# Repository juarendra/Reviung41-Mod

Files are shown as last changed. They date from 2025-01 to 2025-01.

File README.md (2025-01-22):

# Reviung41-Mod
This is MOD for Reviung41 Keyboard

## Table of Content
* [Product Specsification](#product-specsification)
* [Download VIA](#download-via)
* [Load JSON File](#Load-JSON-File)
* [Link Keycode QMK](#Link-keycode-qmk)
* [Tutorial VIA Usage](#tutorial-via-usage)
* [Cara Setting Knob](#cara-setting-knob)
* [How To use MACRO](#how-to-use-macro)
* [Preview Hardware](#preview-hardware)
* [Preview VIA](#preview-via)
* [Cara Update/Upgrade Firmware](#cara-update/upgrade-firmware)
* [Documentation](#documentation)
  * [Pinout Diagram](#pinout-diagram)
  * [Dimension](#dimension)
  * [BOM](#bom)
  * [Schematic](#schematic)
  * [Example Program](#examples-program)
* [FAQ](#FAQ)

## Product Specsification
- Arduino Pro Micro Type C as Microcontroller
- QMK Firmware
- Support VIA, all key can proggrammed
- RGB Underglow or RGB Matrix per key
- 4x Layer 
- Hotswap Switch
- 3D Case 
- Reviung41 Layout
- OLED Screen 

## Download VIA
Link Download VIA(CHOSEE BASED YOUR OS) : https://github.com/the-via/releases/releases
VIA WEB VERSION : https://usevia.app/

## Link Keycode QMK
- mouse : https://github.com/qmk/qmk_firmware/blob/master/docs/feature_mouse_keys.md
- keyboard : https://github.com/qmk/qmk_firmware/blob/master/docs/keycodes.md

## Tutorial VIA Usage
- https://docs.keeb.io/via

## Cara Setting Knob
- Untuk melakukan setting di knob perlu memasukan command berupa keycode qmk, Jadi cara nya sama dengan melakuykan setting dengan Any key seperti petunjuk pada link berikut: 
https://docs.keeb.io/via

Here's some examples:

- LALT(KC_TAB) - Sends Alt-Tab
- LCTL(KC_C) - Sends Ctrl-C
- LGUI(KC_C) - Sends Cmd-C or Win-C
- LSFT(LCTL(KC_END)) - Sends Shift-Ctrl-End
- MO(1) - Momentarily turn on layer 1
- LCA(KC_DEL) - Sends Ctrl-Alt-Del
- MT(MOD_RSFT, KC_ENT) - Sends Shift if held, Enter if tapped
- MACRO (0) - macro 0

## How To use MACRO
you can read on [this file](https://github.com/juarendra/STREAMPAD-QMK-VIA/blob/main/DOC/MACRO%20VIA%20USAGE.pdf)
or you can read on this [web](https://www.keychron.com/blogs/archived/how-to-use-via-to-program-your-keyboard)
or you can see video [youtube](https://youtu.be/GtSeo69Y0Zw)

## Preview Hardware
<p align="center">
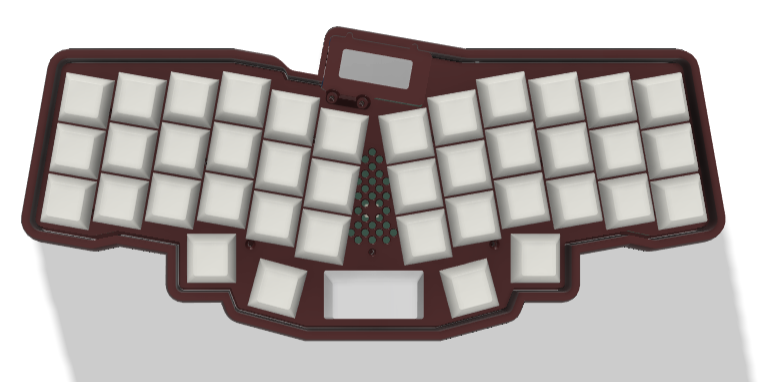
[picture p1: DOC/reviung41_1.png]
  
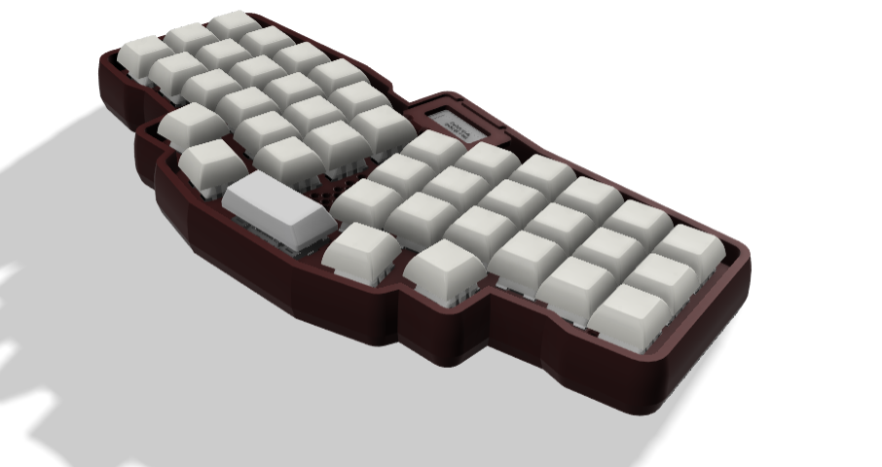
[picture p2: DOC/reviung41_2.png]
  
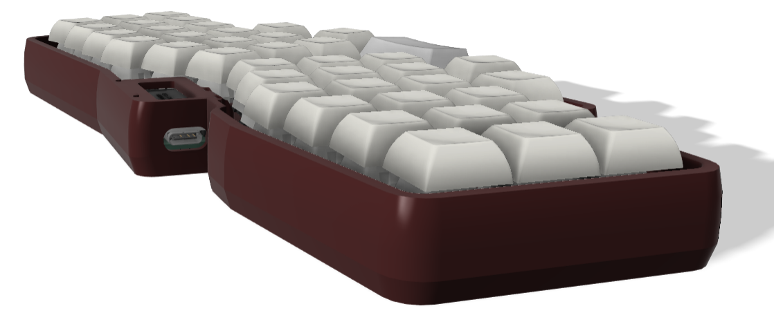
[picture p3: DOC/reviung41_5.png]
  
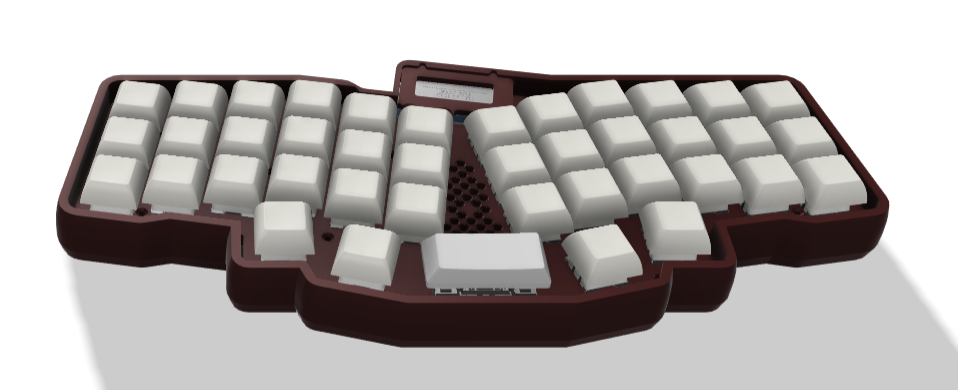
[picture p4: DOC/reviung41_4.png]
  
</p>

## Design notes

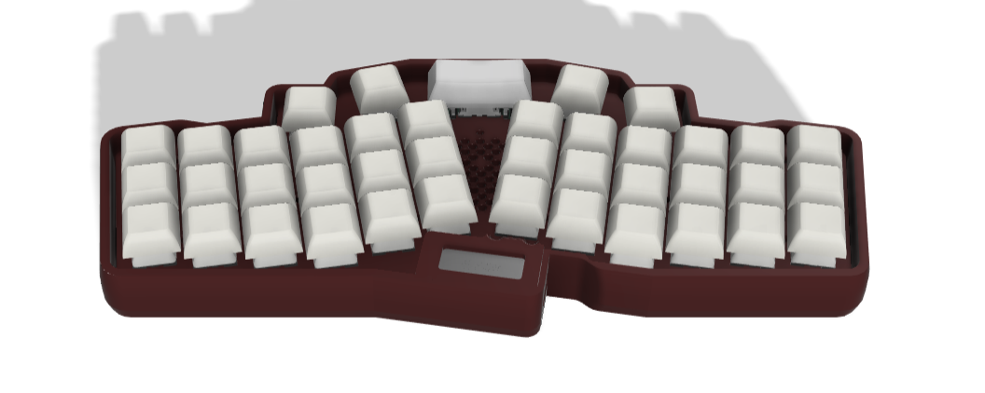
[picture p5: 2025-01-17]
DOC/reviung41_3.png

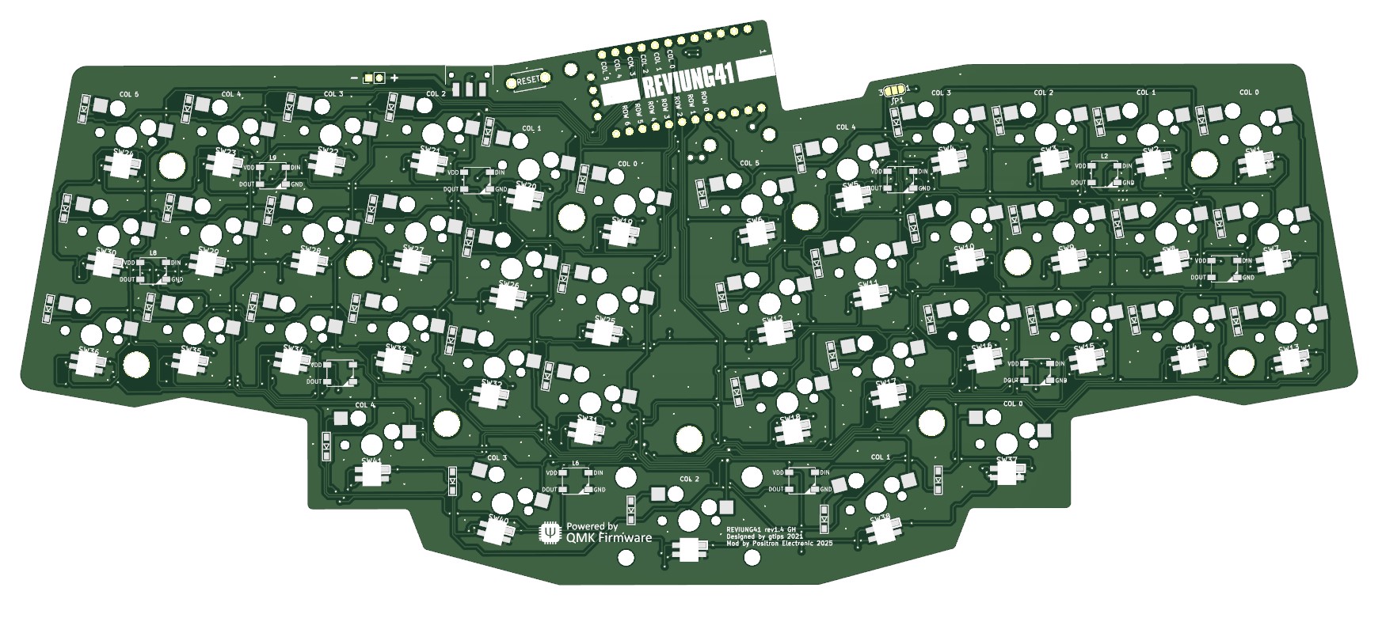
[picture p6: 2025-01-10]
DOC/BOTTOM_PCB.jpg

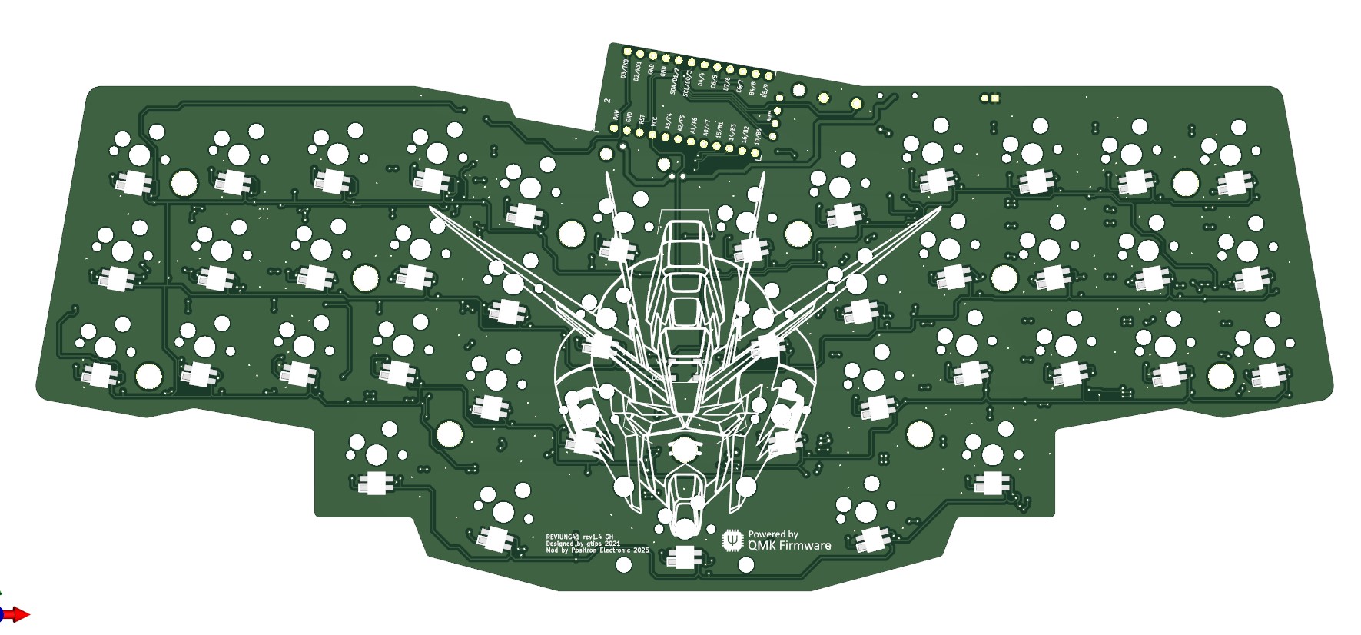
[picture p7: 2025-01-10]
DOC/TOP_PCB.jpg

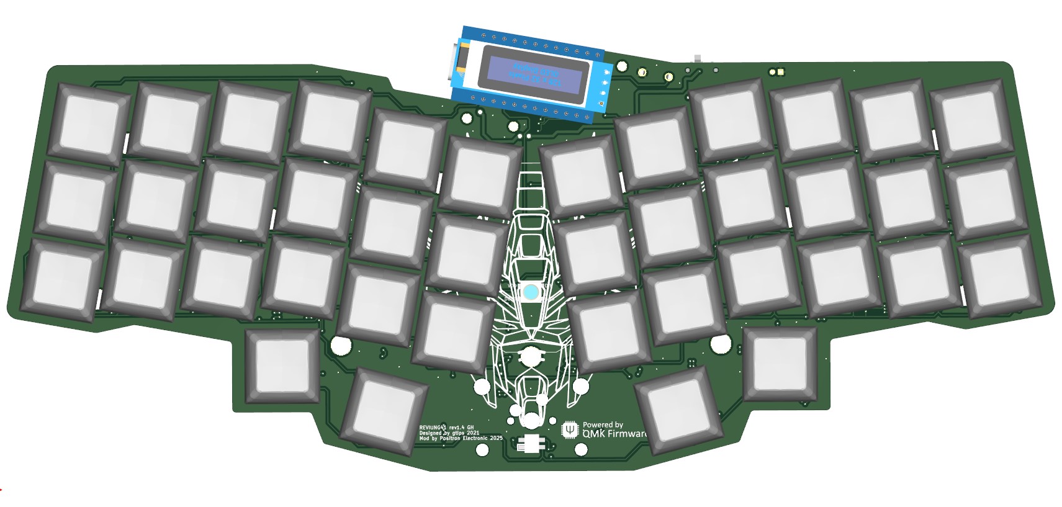
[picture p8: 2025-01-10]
DOC/TOP_PCB1.jpg

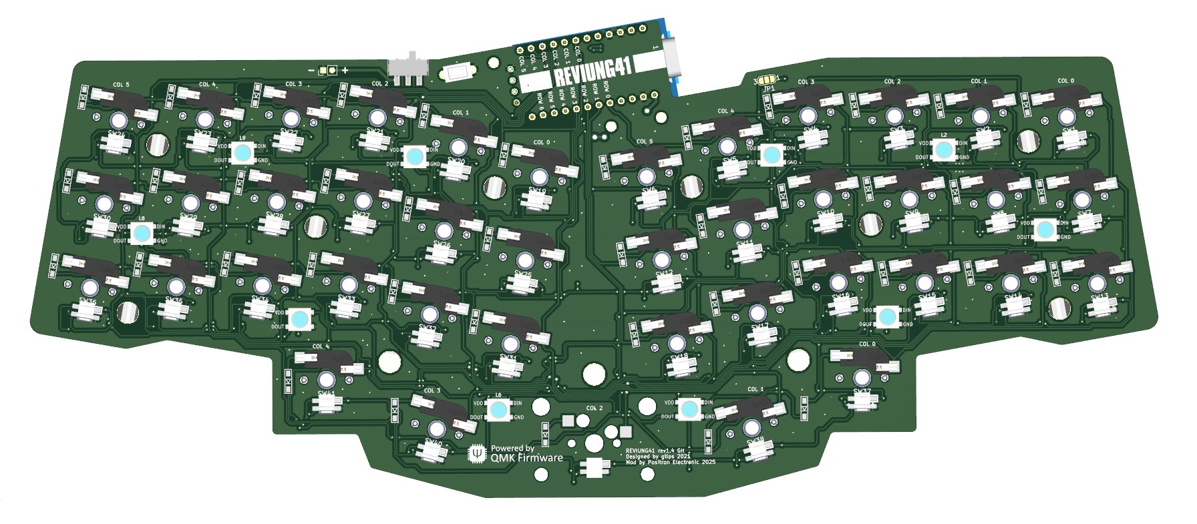
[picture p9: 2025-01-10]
DOC/BOTTOM_PCB1.jpg

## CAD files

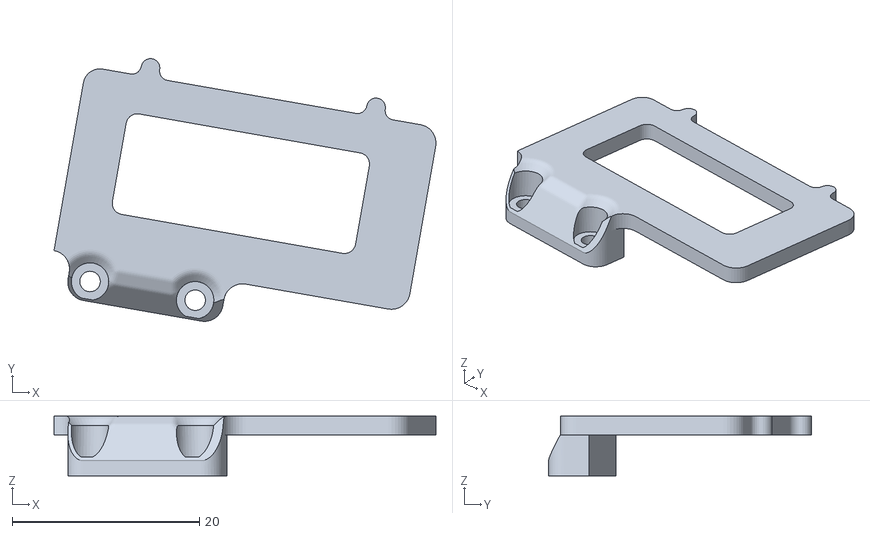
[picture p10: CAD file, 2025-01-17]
HARDWARE/CASE/Oled_case_reviung41.stl
40.8 x 28.1 x 6.36

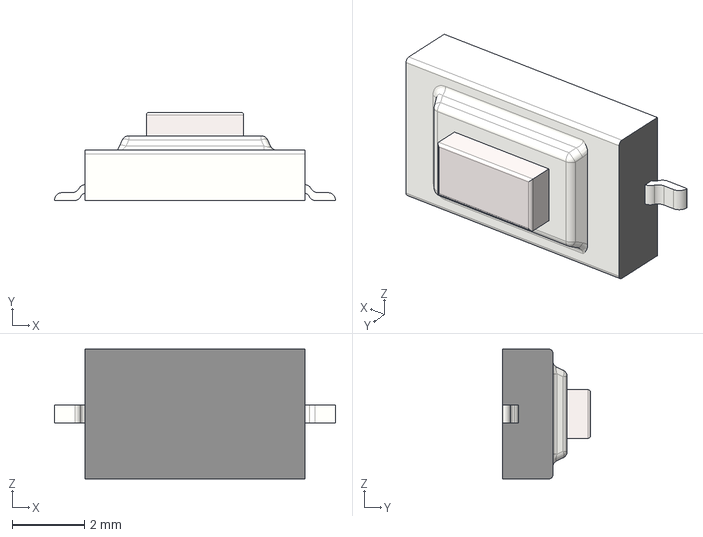
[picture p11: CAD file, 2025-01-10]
HARDWARE/PCB/ver1.4/3d/TactileButton(6x3,5mm)_SMD.stp
7.80 x 2.45 x 3.60 mm

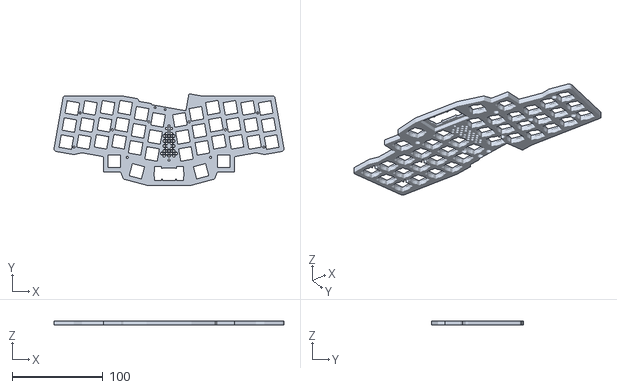
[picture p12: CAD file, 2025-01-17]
HARDWARE/CASE/Plate_reviung41.stl
253.3 x 100.8 x 4.85

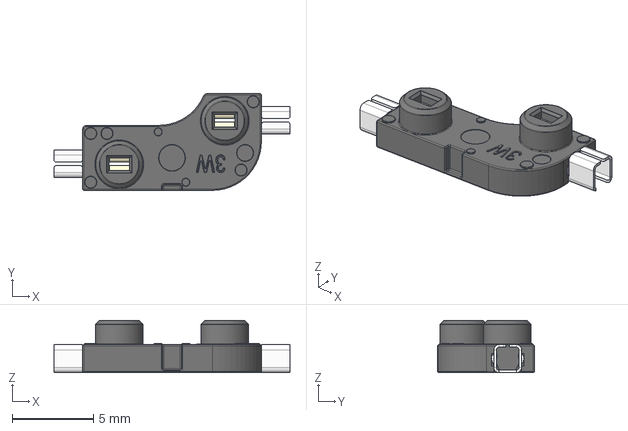
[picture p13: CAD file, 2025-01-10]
HARDWARE/PCB/ver1.4/3d/Kailh Hotswap MX v22.step
14.5 x 5.95 x 3.22 mm

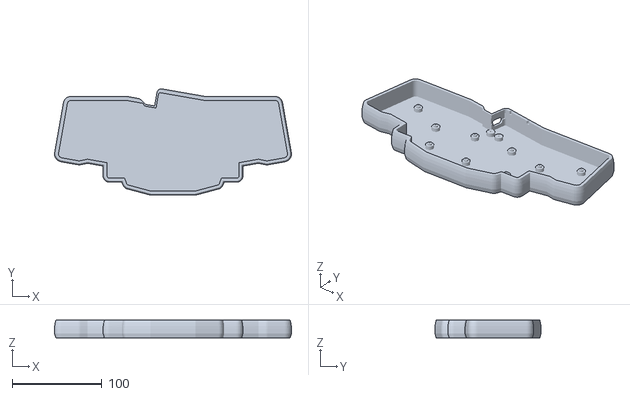
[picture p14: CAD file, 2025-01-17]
HARDWARE/CASE/Case_reviung41.stl
264.0 x 118.3 x 19.9

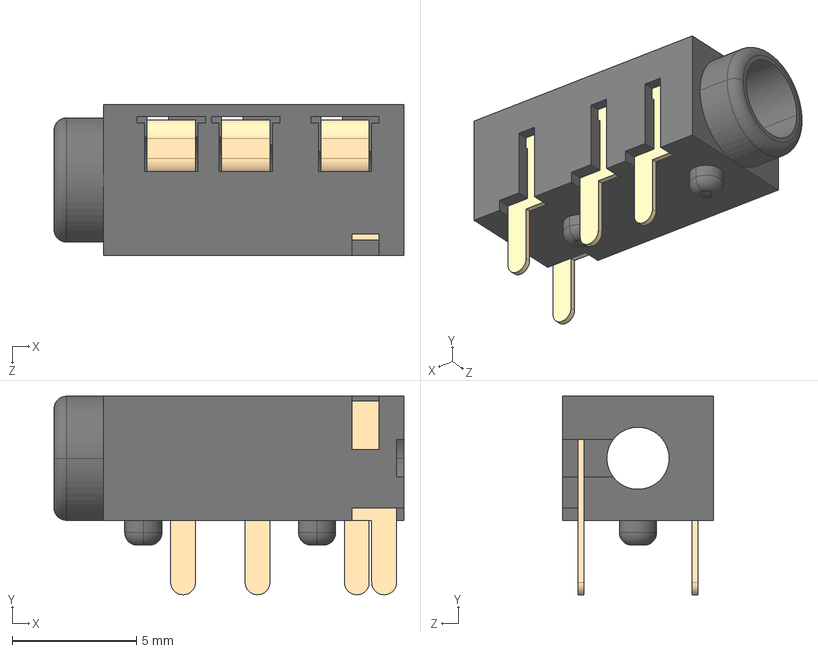
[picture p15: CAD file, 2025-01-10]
HARDWARE/PCB/ver1.4/3d/PJ320A.STEP
14.1 x 8.00 x 6.10 mm
PJ320A蝶褲
PJ320A-Pin-A x 3
PJ320A-Pin-B

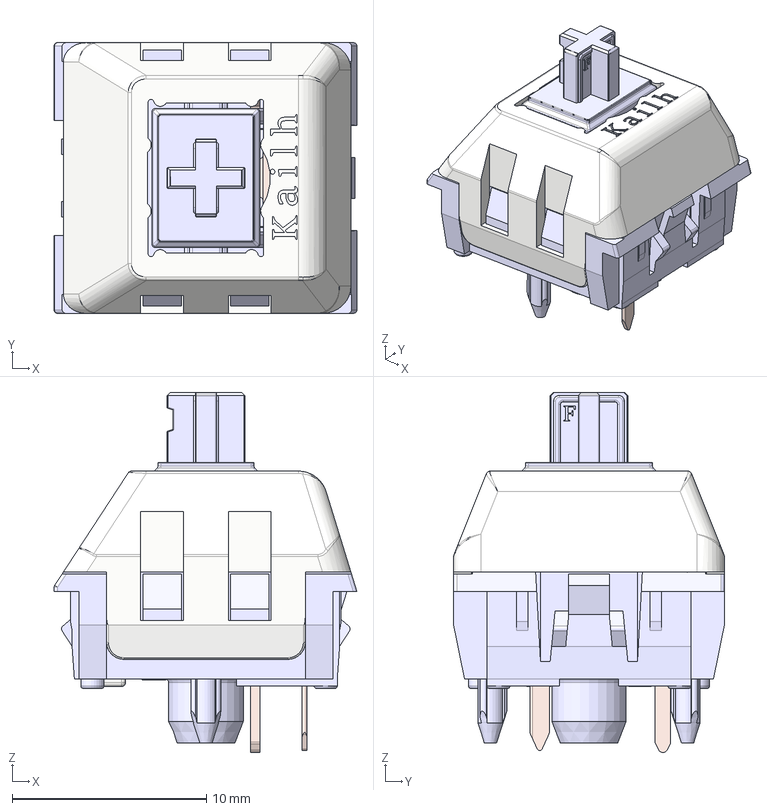
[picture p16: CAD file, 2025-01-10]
HARDWARE/PCB/ver1.4/3d/Kailh Polia.step
15.6 x 14.0 x 18.5 mm
Housing
ThickContact
SpringContact
Stem
Lid

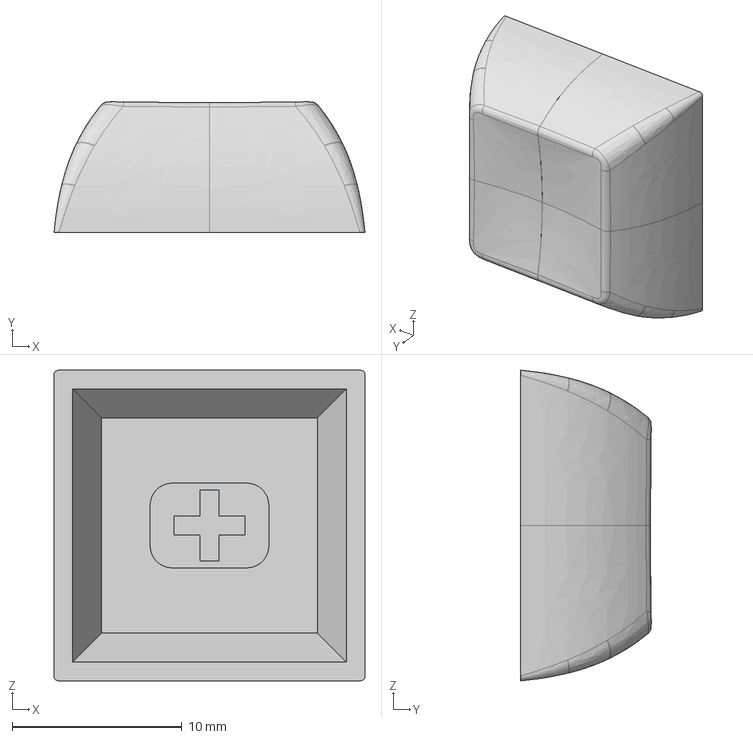
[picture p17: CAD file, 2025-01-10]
HARDWARE/PCB/ver1.4/3d/DSA_Keycap_CherryMX.step
18.3 x 7.69 x 18.3 mm

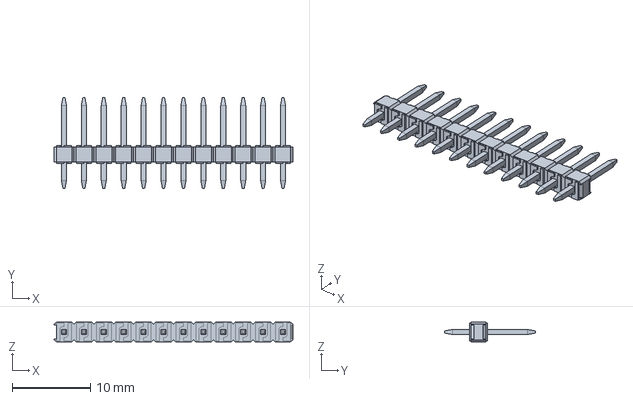
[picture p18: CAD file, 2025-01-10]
HARDWARE/PCB/ver1.4/3d/22-28-4123.stp
30.5 x 11.6 x 2.49 mm

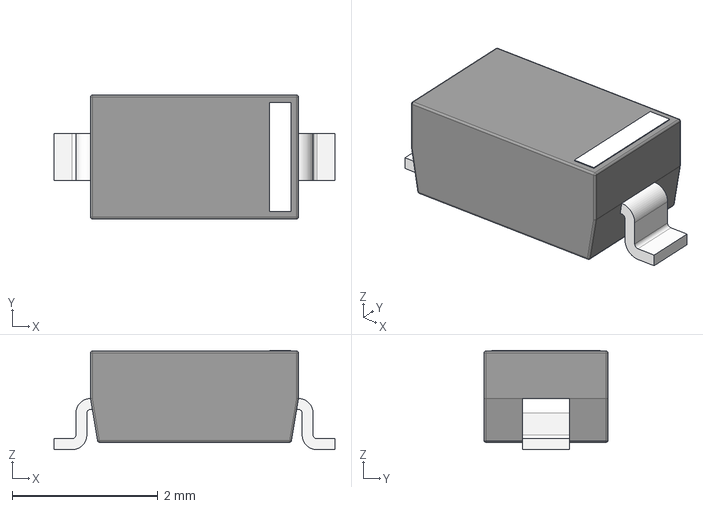
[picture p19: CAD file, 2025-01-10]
HARDWARE/PCB/ver1.4/3d/SOD-123.step
3.85 x 1.70 x 1.36 mm

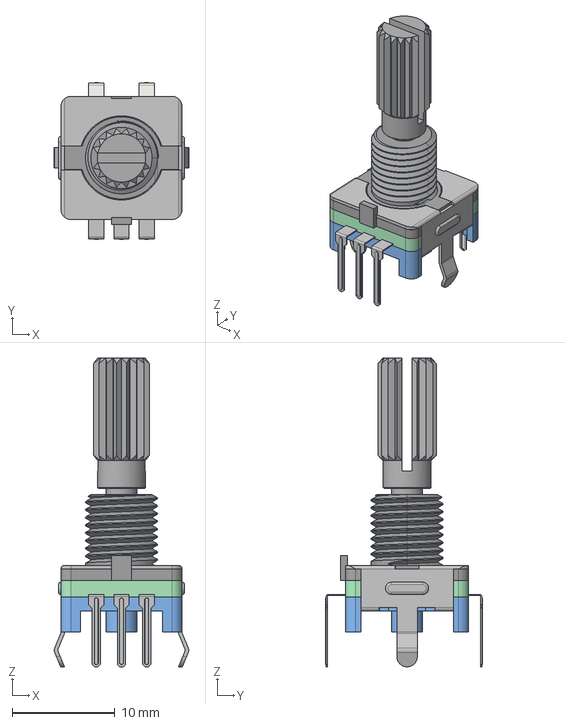
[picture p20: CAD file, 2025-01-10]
HARDWARE/PCB/ver1.4/3d/EC11_Rotary_Encoder_Switched.step
13.1 x 15.3 x 30.1 mm

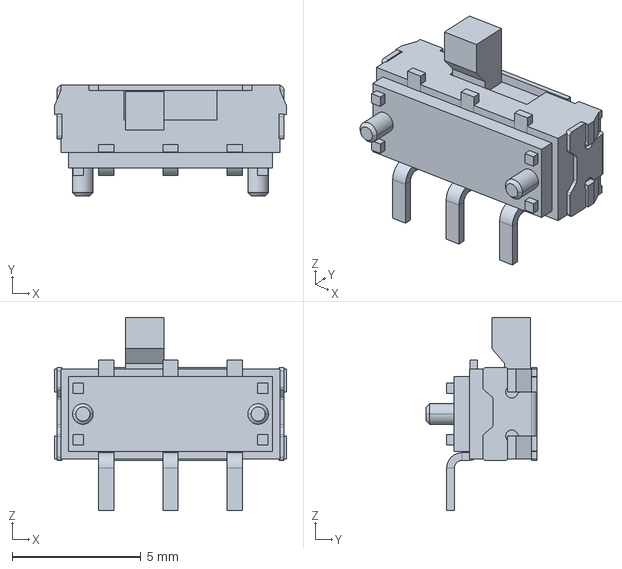
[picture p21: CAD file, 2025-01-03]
HARDWARE/PCB/ver1.4/3d/JS102011SAQN--3DModel-Eagle-1 (1).STEP
9.00 x 4.30 x 7.50 mm

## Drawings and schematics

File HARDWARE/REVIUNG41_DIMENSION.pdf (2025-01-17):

118.28 264.01

19.74 | 2. SIDE VIEW | 1. TOP VIEW ³. SIDE VIEW 4. SIDE VIEW | 6. SIDE VIEW | 5. ISOMETERIC VIEW

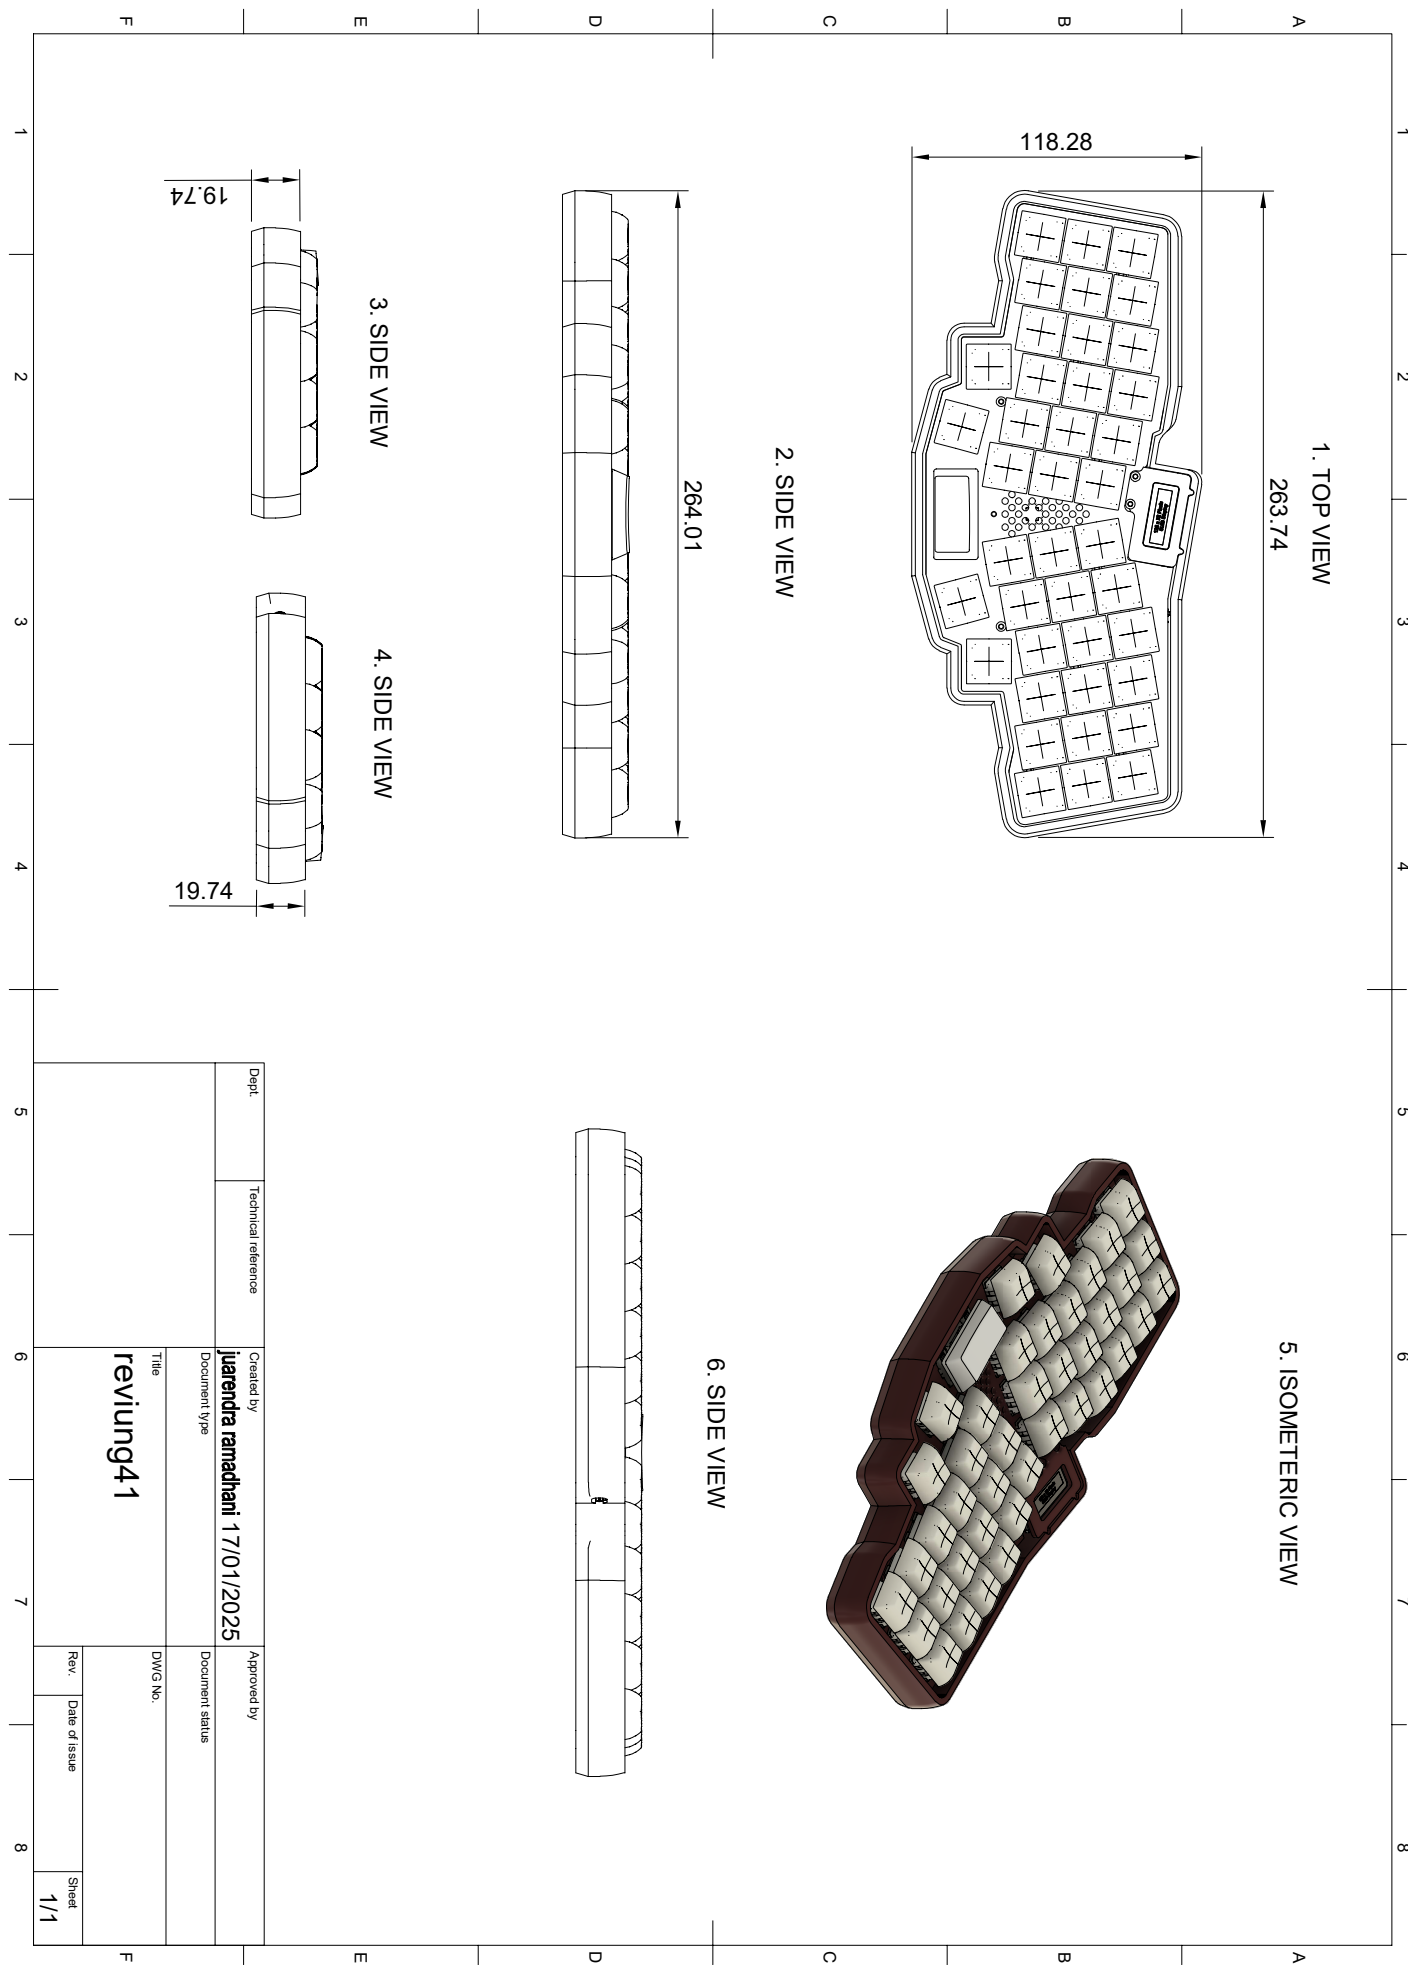
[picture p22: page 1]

1 A 2 3 4 5 6 7 8 1 2 3 4 5 6 7 8 FEDCB FEDCBA Dept. Technical reference Created by Approved by Title DWG No. Document type Document status Rev. Date of issue Sheet 17/01/2025 1/1 reviung41 263.74

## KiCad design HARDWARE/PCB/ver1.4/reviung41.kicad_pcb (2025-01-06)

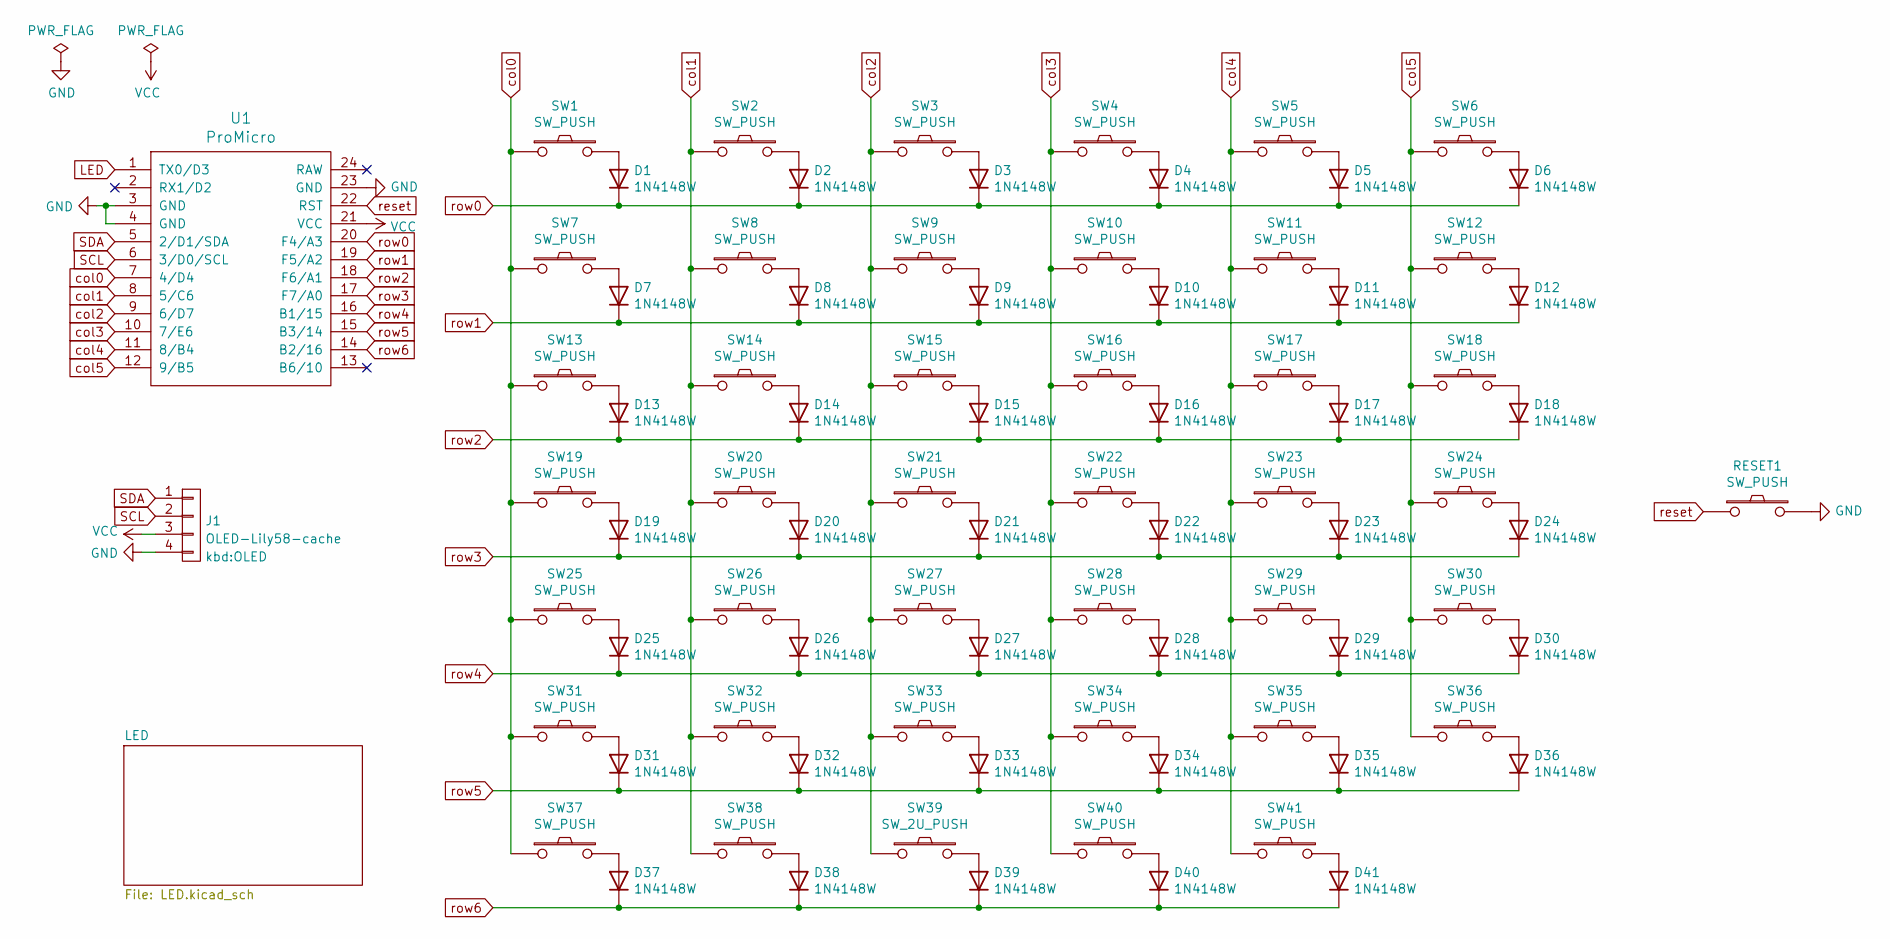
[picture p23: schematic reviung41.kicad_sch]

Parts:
D1, D2, D3, D4, D5, D6, D7, D8, D9, D10, D11, D12, D13, D14, D15, D16, D17, D18, D19, D20, D21, D22, D23, D24, D25, D26, D27, D28, D29, D30, D31, D32, D33, D34, D35, D36, D37, D38, D39, D40, D41: 1N4148W; D3_SMD_1side
J1: OLED-Lily58-cache; OLED
RESET1: SW_PUSH; ResetSW_1side
SW1, SW2, SW3, SW4, SW5, SW6, SW7, SW8, SW9, SW10, SW11, SW12, SW13, SW14, SW15, SW16, SW17, SW18, SW19, SW20, SW21, SW22, SW23, SW24, SW25, SW26, SW27, SW28, SW29, SW30, SW31, SW32, SW33, SW34, SW35, SW36, SW37, SW38, SW40, SW41: SW_PUSH; MXOnly-1U-Hotswap
SW39: SW_2U_PUSH; MXOnly-2U-Hotswap-ReversedStabilizers
U1: ProMicro

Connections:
GND: J1.4, RESET1.2, U1.3 (GND), U1.4 (GND), U1.23 (GND); also elsewhere on the board
LED: U1.1 (TX0/D3); also elsewhere on the board
unnamed: D1.2 (A), SW1.2
unnamed: D2.2 (A), SW2.2
unnamed: D3.2 (A), SW3.2
unnamed: D4.2 (A), SW4.2
unnamed: D5.2 (A), SW5.2
unnamed: D6.2 (A), SW6.2
unnamed: D7.2 (A), SW7.2
unnamed: D8.2 (A), SW8.2
unnamed: D9.2 (A), SW9.2
unnamed: D10.2 (A), SW10.2
unnamed: D11.2 (A), SW11.2
unnamed: D12.2 (A), SW12.2
unnamed: D13.2 (A), SW13.2
unnamed: D14.2 (A), SW14.2
unnamed: D15.2 (A), SW15.2
unnamed: D16.2 (A), SW16.2
unnamed: D17.2 (A), SW17.2
unnamed: D18.2 (A), SW18.2
unnamed: D19.2 (A), SW19.2
unnamed: D20.2 (A), SW20.2
unnamed: D21.2 (A), SW21.2
unnamed: D22.2 (A), SW22.2
unnamed: D23.2 (A), SW23.2
unnamed: D24.2 (A), SW24.2
unnamed: D25.2 (A), SW25.2
unnamed: D26.2 (A), SW26.2
unnamed: D27.2 (A), SW27.2
unnamed: D28.2 (A), SW28.2
unnamed: D29.2 (A), SW29.2
unnamed: D30.2 (A), SW30.2
unnamed: D31.2 (A), SW31.2
unnamed: D32.2 (A), SW32.2
unnamed: D33.2 (A), SW33.2
unnamed: D34.2 (A), SW34.2
unnamed: D35.2 (A), SW35.2
unnamed: D36.2 (A), SW36.2
unnamed: D37.2 (A), SW37.2
unnamed: D38.2 (A), SW38.2
unnamed: D39.2 (A), SW39.2
unnamed: D40.2 (A), SW40.2
unnamed: D41.2 (A), SW41.2
SCL: J1.2, U1.6 (3/D0/SCL)
SDA: J1.1, U1.5 (2/D1/SDA)
VCC: J1.3, U1.21 (VCC); also elsewhere on the board
col0: SW1.1, SW7.1, SW13.1, SW19.1, SW25.1, SW31.1, SW37.1, U1.7 (4/D4)
col1: SW2.1, SW8.1, SW14.1, SW20.1, SW26.1, SW32.1, SW38.1, U1.8 (5/C6)
col2: SW3.1, SW9.1, SW15.1, SW21.1, SW27.1, SW33.1, SW39.1, U1.9 (6/D7)
col3: SW4.1, SW10.1, SW16.1, SW22.1, SW28.1, SW34.1, SW40.1, U1.10 (7/E6)
col4: SW5.1, SW11.1, SW17.1, SW23.1, SW29.1, SW35.1, SW41.1, U1.11 (8/B4)
col5: SW6.1, SW12.1, SW18.1, SW24.1, SW30.1, SW36.1, U1.12 (9/B5)
reset: RESET1.1, U1.22 (RST)
row0: D1.1 (K), D2.1 (K), D3.1 (K), D4.1 (K), D5.1 (K), D6.1 (K), U1.20 (F4/A3)
row1: D7.1 (K), D8.1 (K), D9.1 (K), D10.1 (K), D11.1 (K), D12.1 (K), U1.19 (F5/A2)
row2: D13.1 (K), D14.1 (K), D15.1 (K), D16.1 (K), D17.1 (K), D18.1 (K), U1.18 (F6/A1)
row3: D19.1 (K), D20.1 (K), D21.1 (K), D22.1 (K), D23.1 (K), D24.1 (K), U1.17 (F7/A0)
row4: D25.1 (K), D26.1 (K), D27.1 (K), D28.1 (K), D29.1 (K), D30.1 (K), U1.16 (B1/15)
row5: D31.1 (K), D32.1 (K), D33.1 (K), D34.1 (K), D35.1 (K), D36.1 (K), U1.15 (B3/14)
row6: D37.1 (K), D38.1 (K), D39.1 (K), D40.1 (K), D41.1 (K), U1.14 (B2/16)

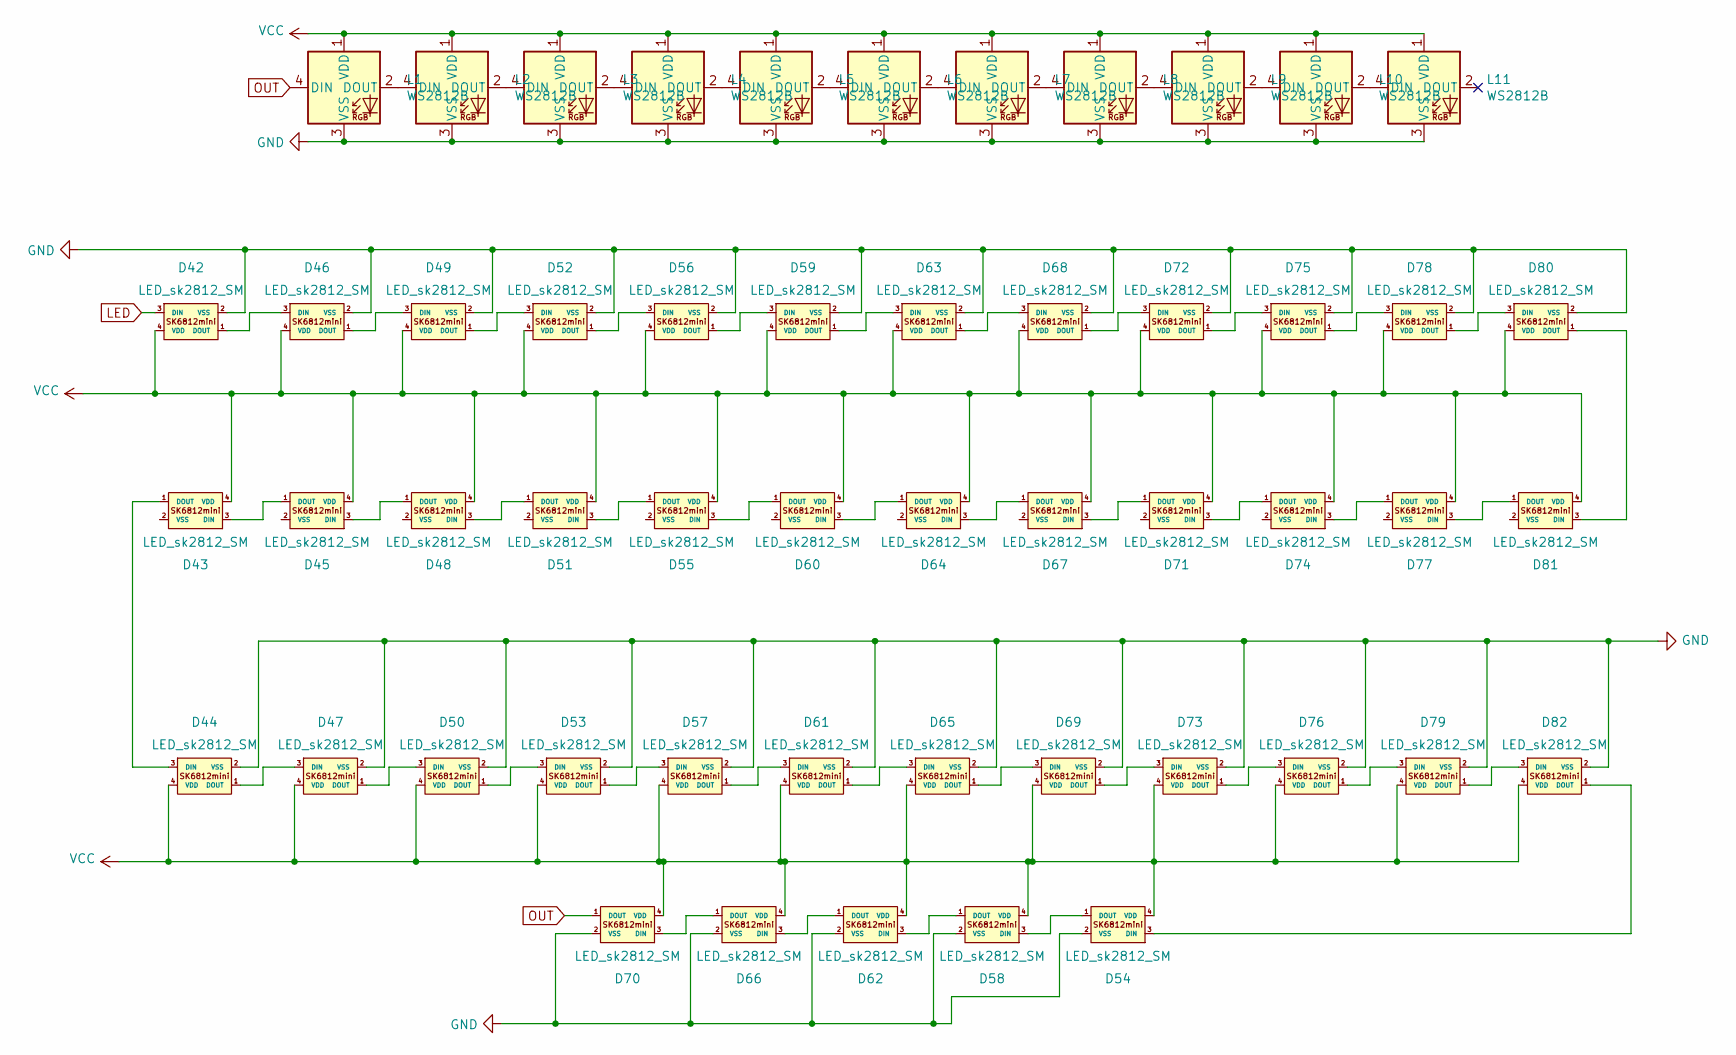
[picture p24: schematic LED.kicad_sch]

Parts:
D42, D43, D44, D45, D46, D47, D48, D49, D50, D51, D52, D53, D54, D55, D56, D57, D58, D59, D60, D61, D62, D63, D64, D65, D66, D67, D68, D69, D70, D71, D72, D73, D74, D75, D76, D77, D78, D79, D80, D81, D82: LED_sk2812_SM; SK6812MINI_and_cherry
L1, L2, L3, L4, L5, L6, L7, L8, L9, L10, L11: WS2812B; LED_WS2812B_PLCC4_5.0x5.0mm_P3.2mm

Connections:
GND: D42.2 (VSS), D44.2 (VSS), D46.2 (VSS), D47.2 (VSS), D49.2 (VSS), D50.2 (VSS), D52.2 (VSS), D53.2 (VSS), D54.2 (VSS), D56.2 (VSS), D57.2 (VSS), D58.2 (VSS), D59.2 (VSS), D61.2 (VSS), D62.2 (VSS), D63.2 (VSS), D65.2 (VSS), D66.2 (VSS), D68.2 (VSS), D69.2 (VSS), D70.2 (VSS), D72.2 (VSS), D73.2 (VSS), D75.2 (VSS), D76.2 (VSS), D78.2 (VSS), D79.2 (VSS), D80.2 (VSS), D82.2 (VSS), L1.3 (VSS), L2.3 (VSS), L3.3 (VSS), L4.3 (VSS), L5.3 (VSS), L6.3 (VSS), L7.3 (VSS), L8.3 (VSS), L9.3 (VSS), L10.3 (VSS), L11.3 (VSS); also elsewhere on the board
LED: D42.3 (DIN); also elsewhere on the board
unnamed: D42.1 (DOUT), D46.3 (DIN)
unnamed: D43.3 (DIN), D45.1 (DOUT)
unnamed: D43.1 (DOUT), D44.3 (DIN)
unnamed: D44.1 (DOUT), D47.3 (DIN)
unnamed: D45.3 (DIN), D48.1 (DOUT)
unnamed: D46.1 (DOUT), D49.3 (DIN)
unnamed: D47.1 (DOUT), D50.3 (DIN)
unnamed: D48.3 (DIN), D51.1 (DOUT)
unnamed: D49.1 (DOUT), D52.3 (DIN)
unnamed: D50.1 (DOUT), D53.3 (DIN)
unnamed: D51.3 (DIN), D55.1 (DOUT)
unnamed: D52.1 (DOUT), D56.3 (DIN)
unnamed: D53.1 (DOUT), D57.3 (DIN)
unnamed: D54.3 (DIN), D82.1 (DOUT)
unnamed: D54.1 (DOUT), D58.3 (DIN)
unnamed: D55.3 (DIN), D60.1 (DOUT)
unnamed: D56.1 (DOUT), D59.3 (DIN)
unnamed: D57.1 (DOUT), D61.3 (DIN)
unnamed: D58.1 (DOUT), D62.3 (DIN)
unnamed: D59.1 (DOUT), D63.3 (DIN)
unnamed: D60.3 (DIN), D64.1 (DOUT)
unnamed: D61.1 (DOUT), D65.3 (DIN)
unnamed: D62.1 (DOUT), D66.3 (DIN)
unnamed: D63.1 (DOUT), D68.3 (DIN)
unnamed: D64.3 (DIN), D67.1 (DOUT)
unnamed: D65.1 (DOUT), D69.3 (DIN)
unnamed: D66.1 (DOUT), D70.3 (DIN)
unnamed: D67.3 (DIN), D71.1 (DOUT)
unnamed: D68.1 (DOUT), D72.3 (DIN)
unnamed: D69.1 (DOUT), D73.3 (DIN)
unnamed: D71.3 (DIN), D74.1 (DOUT)
unnamed: D72.1 (DOUT), D75.3 (DIN)
unnamed: D73.1 (DOUT), D76.3 (DIN)
unnamed: D74.3 (DIN), D77.1 (DOUT)
unnamed: D75.1 (DOUT), D78.3 (DIN)
unnamed: D76.1 (DOUT), D79.3 (DIN)
unnamed: D77.3 (DIN), D81.1 (DOUT)
unnamed: D78.1 (DOUT), D80.3 (DIN)
unnamed: D79.1 (DOUT), D82.3 (DIN)
unnamed: D80.1 (DOUT), D81.3 (DIN)
unnamed: L1.2 (DOUT), L2.4 (DIN)
unnamed: L2.2 (DOUT), L3.4 (DIN)
unnamed: L3.2 (DOUT), L4.4 (DIN)
unnamed: L4.2 (DOUT), L5.4 (DIN)
unnamed: L5.2 (DOUT), L6.4 (DIN)
unnamed: L6.2 (DOUT), L7.4 (DIN)
unnamed: L7.2 (DOUT), L8.4 (DIN)
unnamed: L8.2 (DOUT), L9.4 (DIN)
unnamed: L9.2 (DOUT), L10.4 (DIN)
unnamed: L10.2 (DOUT), L11.4 (DIN)
OUT: D70.1 (DOUT), L1.4 (DIN)
VCC: D42.4 (VDD), D43.4 (VDD), D44.4 (VDD), D45.4 (VDD), D46.4 (VDD), D47.4 (VDD), D48.4 (VDD), D49.4 (VDD), D50.4 (VDD), D51.4 (VDD), D52.4 (VDD), D53.4 (VDD), D54.4 (VDD), D55.4 (VDD), D56.4 (VDD), D57.4 (VDD), D58.4 (VDD), D59.4 (VDD), D60.4 (VDD), D61.4 (VDD), D62.4 (VDD), D63.4 (VDD), D64.4 (VDD), D65.4 (VDD), D66.4 (VDD), D67.4 (VDD), D68.4 (VDD), D69.4 (VDD), D70.4 (VDD), D71.4 (VDD), D72.4 (VDD), D73.4 (VDD), D74.4 (VDD), D75.4 (VDD), D76.4 (VDD), D77.4 (VDD), D78.4 (VDD), D79.4 (VDD), D80.4 (VDD), D81.4 (VDD), D82.4 (VDD), L1.1 (VDD), L2.1 (VDD), L3.1 (VDD), L4.1 (VDD), L5.1 (VDD), L6.1 (VDD), L7.1 (VDD), L8.1 (VDD), L9.1 (VDD), L10.1 (VDD), L11.1 (VDD); also elsewhere on the board

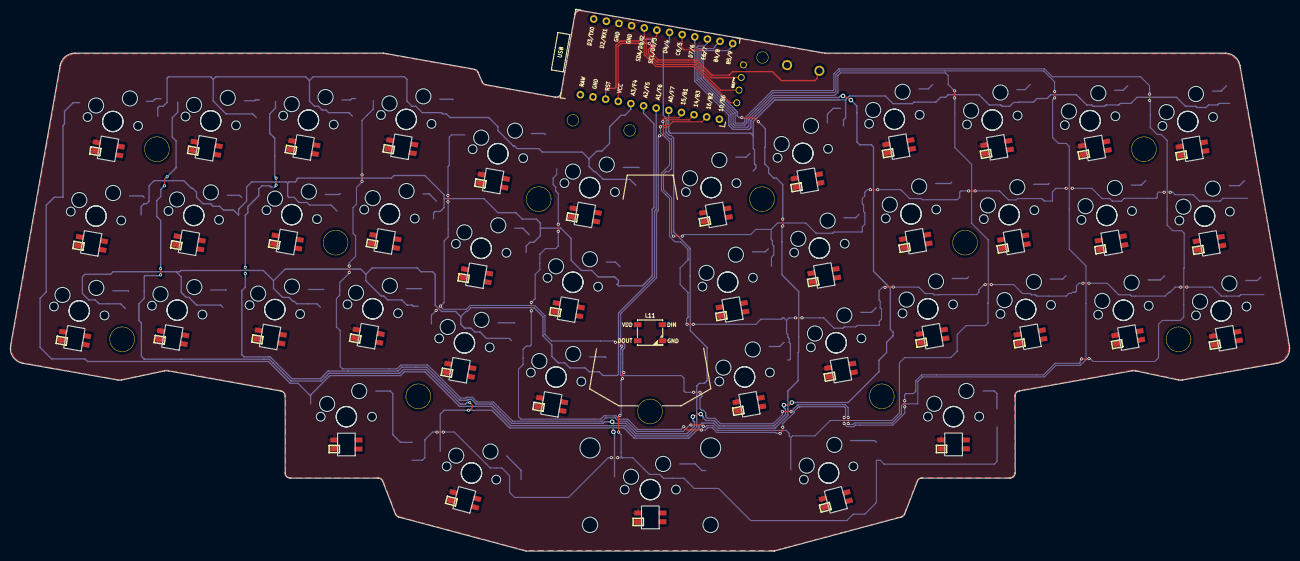
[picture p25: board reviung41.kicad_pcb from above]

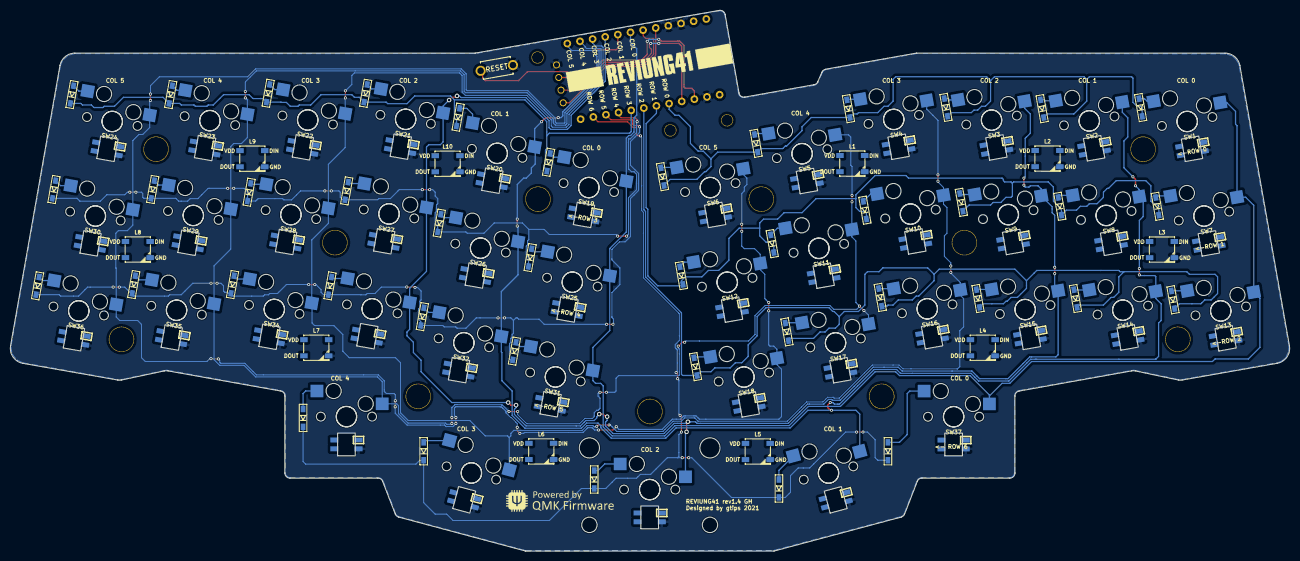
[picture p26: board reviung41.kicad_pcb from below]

Board: 2 copper layers, 253.3 x 107.1 mm, 151 parts (52 on the bottom side), 111 nets.

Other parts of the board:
H1: H1; HOLE
H2: H2; HOLE
H3: H3; HOLE
H4: H4; HOLE
H5: H5; HOLE
H6: H6; HOLE
H7: H7; HOLE
H8: H8; HOLE
H9: H9; HOLE
H10: H10; HOLE
H11: H11; HOLE
H12: H12; HOLE_2.2mm
H13: H13; HOLE_2.2mm
H14: H14; HOLE_2.2mm

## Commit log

2025-01-05 FEAT: re wiring switch
    [reviung41.kicad_pcb]
2025-01-06 FEAT: re wiring OLED and Reset Button
    [reviung41.kicad_pcb]
2025-01-07 FEAT: re wiring led rgb per key
2025-01-08 FEAT: add switch, connector battery and create gerber
    [reviung41-B_Cu.gbl, reviung41-B_Mask.gbs, reviung41-B_Silkscreen.gbo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]
2025-01-08 FEAT: add selector for underglow or matrix
    [LED.kicad_sch, reviung41.kicad_sch]
2025-01-10 FEAT: add 3d Model
    [22-28-4123.stp, DSA_Keycap_CherryMX.step, EC11_Rotary_Encoder_Switched.step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]
2025-01-17 FEAT: add Case 3D file and Image of rendering
    [Case_reviung41.stl, Oled_case_reviung41.stl, Plate_reviung41.stl]
